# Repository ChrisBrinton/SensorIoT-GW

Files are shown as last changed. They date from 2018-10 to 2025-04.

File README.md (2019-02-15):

# SensorIoT-GW

The SensorIoT GW project is the set of PCB files and the firmware for the the gateway element of the SensorIoT system. It uses an ESP8266 for MCU and Wifi capabilities and an RFM69 packet radio for communicating with the battery operated nodes.

## PCB cad files
Are located in the PCBs folder and use EAGLE cad format (more info [here](https://www.autodesk.com/products/eagle/overview))

## Firmware
More info in the firmware folder.

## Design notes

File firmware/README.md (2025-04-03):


# The firmware for the SensorIoT GW

The firmware is based on Xose Perez project [RFM69GW](https://bitbucket.org/xoseperez/rfm69gw) which has been modified to include a display as well as working with the SensorIoT App and server side as well as moving to the RFM95 Lora radio.

## Installation

### Prerequisits
The firmware project uses Platformio to manage and build. The recommended environment for running Platformio is [VSCode](https://code.visualstudio.com/). After installing VSCode, you can search for the Platformio Extension and install. Platformio can be used command line only if needed. Further details can be found at [Platformio.org](https://platformio.org/)

You'll need the VCP (Virtual Com Port) drivers from [here](https://www.silabs.com/products/development-tools/software/usb-to-uart-bridge-vcp-drivers)

And of course you'll need [git](https://www.git-scm.com/downloads) and [node](https://nodejs.org/en/) if you dont have already

Then the following will install the repo and build:

    git clone https://github.com/ChrisBrinton/SensorIoT-GW
    cd SensorIoT-GW/firmware
    npm install
    pio run

If the build fails due to errors such as

    .pio\libdeps\node\ESP Async WebServer_ID306\src\WebHandlers.cpp:78:25: error: 'time' was not declared in this scope

You'll need to remove .pio\libdeps\node\Time_ID44\Time.h. This error happens on windows due to a lack of case sensitivity between Time.h (not needed for this project) and time.h (needed for this project)

To deploy to your device you need to upload both the SPIFFS filesystem that contains the static web data and the initial settings, then the firmware code:
    To build the static web pages:
        gulp
    To upload filesystem (including static web pages):
        pio run --target uploadfs -e node
    To upload firmware:
        pio run --target upload -e node

## Publishing

The GW publishes to MQTT in the following way:

The topic format for our backend looks like:
/<prefix>/<hostname>/<node_id>/<data_type>/<data>

 <prefix> is GDESGW1 for no particular reason other than I needed something to differentiate messages at a high level in case I wanted to use the broker for a completely different set of messages. For those trivia minded, it stands for GeekDayEnvironmentSensorGateWay model 1

<hostname> is a unique 6 digit number. Just pick one for each independent MQTT publisher

<node_id> is for each differentiated sensor cluster from the hostname. So you could publish two different temp readings from the same MQTT publisher by changing the node #

<data_type> is the sensor data type along the lines of H for humidity, P for pressure and F for temperature (sorry metric users)

<data> is the (presumably) numeric value (assumed to be a float of not too many decimal places)

There are a couple of builtin monitoring data types as well that can be safely ignored if you arent using my hardware: BAT for battery voltage and RSSI for signal strength of the node

That all boils down to a real message that looks like:
/GDESGW1/141188/1/F/78.33

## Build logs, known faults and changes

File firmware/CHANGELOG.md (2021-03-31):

# SensorIoT-GW change log

## [1.1.6]

### Added
- Logging for webserver in hopes of tracking down stability issues

### Changed
- Display Batt values for 3V battery (2xAA) battery more correctly
### Fixed
- Set NTP config to be correct for USA.
## [1.1.5]
### Changed

- Updated settings save to only restart Wifi if Wifi settings changed.
- Heartbeat the heap size even if not connected to MQTT

### Fixed

- Disable local DNS server in AP mode as there is a memory leak that needs to be tracked down.

## [1.1.4]
### Changed

- Updated the following to improve TCP stability
    - Updated platformio core to 2.2.3 (arduino core 2.5.2)
    - Updated ESPAsyncTCP to 1.2.2
    - Updated ESP Async WebServer to 1.2.3
    - Updated RadioHead@1.97 (required for new esp/platformio core)

## [1.1.3]
### Fixed

- Updated NtpClientLib to current version to resolve issue with USA DST calculation

## [1.1.2]

### Changed

- Updated MQTT keepalive time to 240s to be creater than ping interval (60s) on branch using RadioHead radio lib

## [1.0.10] 10/22/2019

### Changed

- Updated MQTT keepalive time to 240s to be creater than ping interval (60s) on branch using lowpowerlab radio lib

## [1.1.1] 9/26/2019

### Changed

- Moved to Radiohead radio library so support RFM95 LoRa radios. This is a pin compatible radio to the RFM69HCW which was used in the previous HW.

### Added

- Supports LTR-329 ambient light sensor and digipot controlled display voltage. This is new in GW HW 1.15 and above. The ambient light is measured using the sensor and the display is adjusted based on this value and the display brightness setting which has been added to the config web pages in the display section.
- The radiohead library is used in the reliable datagram mode where the nodes and the GW exchange ACKs to confirm message receipt. The ACKing will stop on the node side after some number of minutes to conserve node battery life. While the ACKs are happening, TX strength on the node side is tuned.

### Fixed

- Fixed bug in nodelist that caused a crash when deleting an element.

## [1.0.9] 6/18/2019

### Changed

- Reorganized main display code to move slowly side to side (1px/m) to wear OLED displays evenly.
- Updated startup logo to SensorIoT

### Added

- Display has optional shutdown hours, configurable in web config

### Fixed

- Locked platformio core to 2.0.4 to resolve instability

## [1.0.8] 2/18/2019

### Changed

- Updated JustWifi lib to 2.0.2 and refactored to support
- Updated backwards compatible libs to current versions:
  - AsyncMqttClient@0.8.2
  - ESPAsyncTCP@1.2.0
  - ArduinoJson@5.13.4
  - Adafruit GFX Library@b920674
  - ES PAsync WebServer@1.2.0
  - NtpClientLib@2.5.1
  - Sparkfun BME280@2.0.4
  - RFM69@ebf2cb86ff
- Installation directions more complete

### Fixed

- Updated platformio.ini to fix ESP Async WebServer and RFM69 lib defs
- Changed battery thresholds to be more accomodating to 1.5v battery ranges.

### Added

- GW now retrieves nickname from server via MQTT and displays the shortname when available rather than ID:#

## [1.0.7] 1/10/2019

### Added

- Completed support for http firmware upload for both FW and SPIFFS

### Changed

- Display logic is now non-blocking

## [1.0.6] 1/2/2019

### Added

- Initial support for http firmware upload

## [1.0.5] 12/20/2018

### Fixed

- Convert getTopicMapping to string from char\* in effort to eliminate bad topic publishes
- Fix for display of time ending in 1/4/9 shifting and not being centered.

## [1.0.4] 10/1/2018

### Added

- Add erase all firmware function to settings - bring firmware back to factory default

## [1.0.3] 7/1/2018

### Added

- Added display logic to show node 1 data and received node info on display while in AP mode. This allows full HW testing without configuring wifi

### Changed

- Publish node 1 data to MQTT. Packet parsing reworked to facilitate.

## [1.0.0] 7/1/2017

### Added

- Initial version
- Fork of [RFM69GW](https://bitbucket.org/xoseperez/rfm69gw/overview) by Xose Perez over on bitbucket
- Added 128x32 pixel OLED display (based on SSD1305 display driver) to show time and node data

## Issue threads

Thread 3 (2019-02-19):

Add support for LoRa radios

ChrisBrinton, 2019-02-19:
The current RFM69 library used (from lowpowerlabs) does not support the RFM95 LoRa radios. The GW should either move to the rocketlabs library (that supports both) or at least use it to support RFM95 radios. Needs investigation to determine best route.

ChrisBrinton, 2019-02-19:
The suggested lib is [RadioHead](https://www.airspayce.com/mikem/arduino/RadioHead/index.html)

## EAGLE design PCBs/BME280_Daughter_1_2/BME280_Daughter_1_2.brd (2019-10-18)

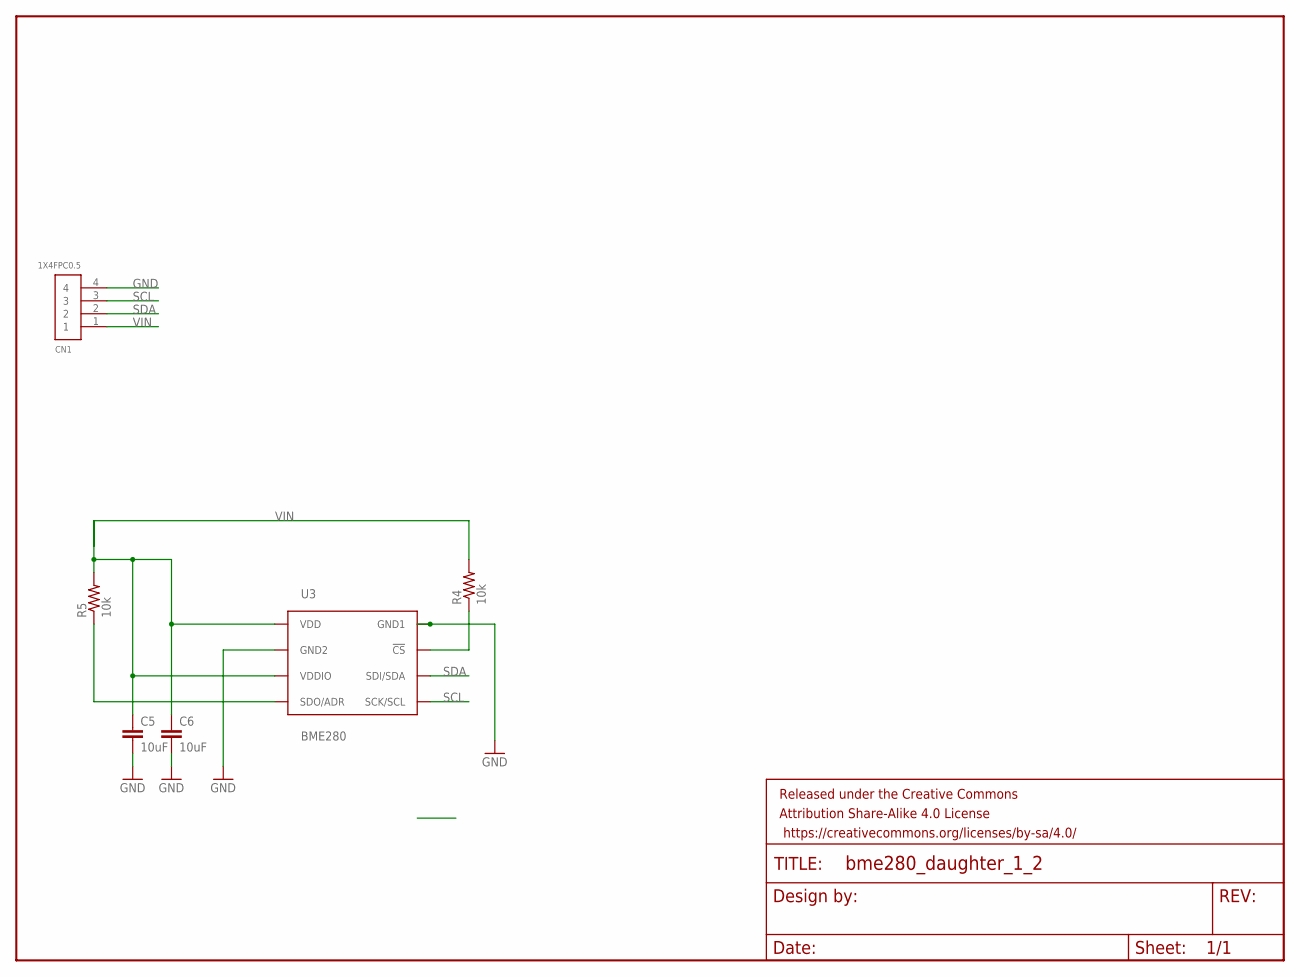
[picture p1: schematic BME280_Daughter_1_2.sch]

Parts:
C5, C6: 10uF; 0805
CN1: 1X4FPC0.5; FPC_0.5MM-4
FRAME1: FRAME-LETTER; CREATIVE_COMMONS
R4, R5: 10k; 0805
U3: BME280; BME280_LGA

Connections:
GND: C5.2, C6.2, CN1.4, U3.P$1 (GND1), U3.P$7 (GND2)
unnamed: R4.1, U3.P$2 (!CS)
unnamed: R5.1, U3.P$5 (SDO/ADR)
SCL: CN1.3, U3.P$4 (SCK/SCL)
SDA: CN1.2, U3.P$3 (SDI/SDA)
VIN: C5.1, C6.1, CN1.1, R4.2, R5.2, U3.P$6 (VDDIO), U3.P$8 (VDD)

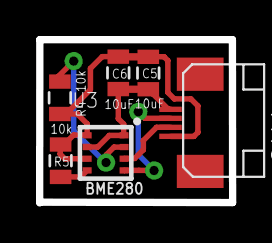
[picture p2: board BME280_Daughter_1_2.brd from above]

Board: 2 copper layers, 10.7 x 9.1 mm, 7 parts (0 on the bottom side), 6 nets.

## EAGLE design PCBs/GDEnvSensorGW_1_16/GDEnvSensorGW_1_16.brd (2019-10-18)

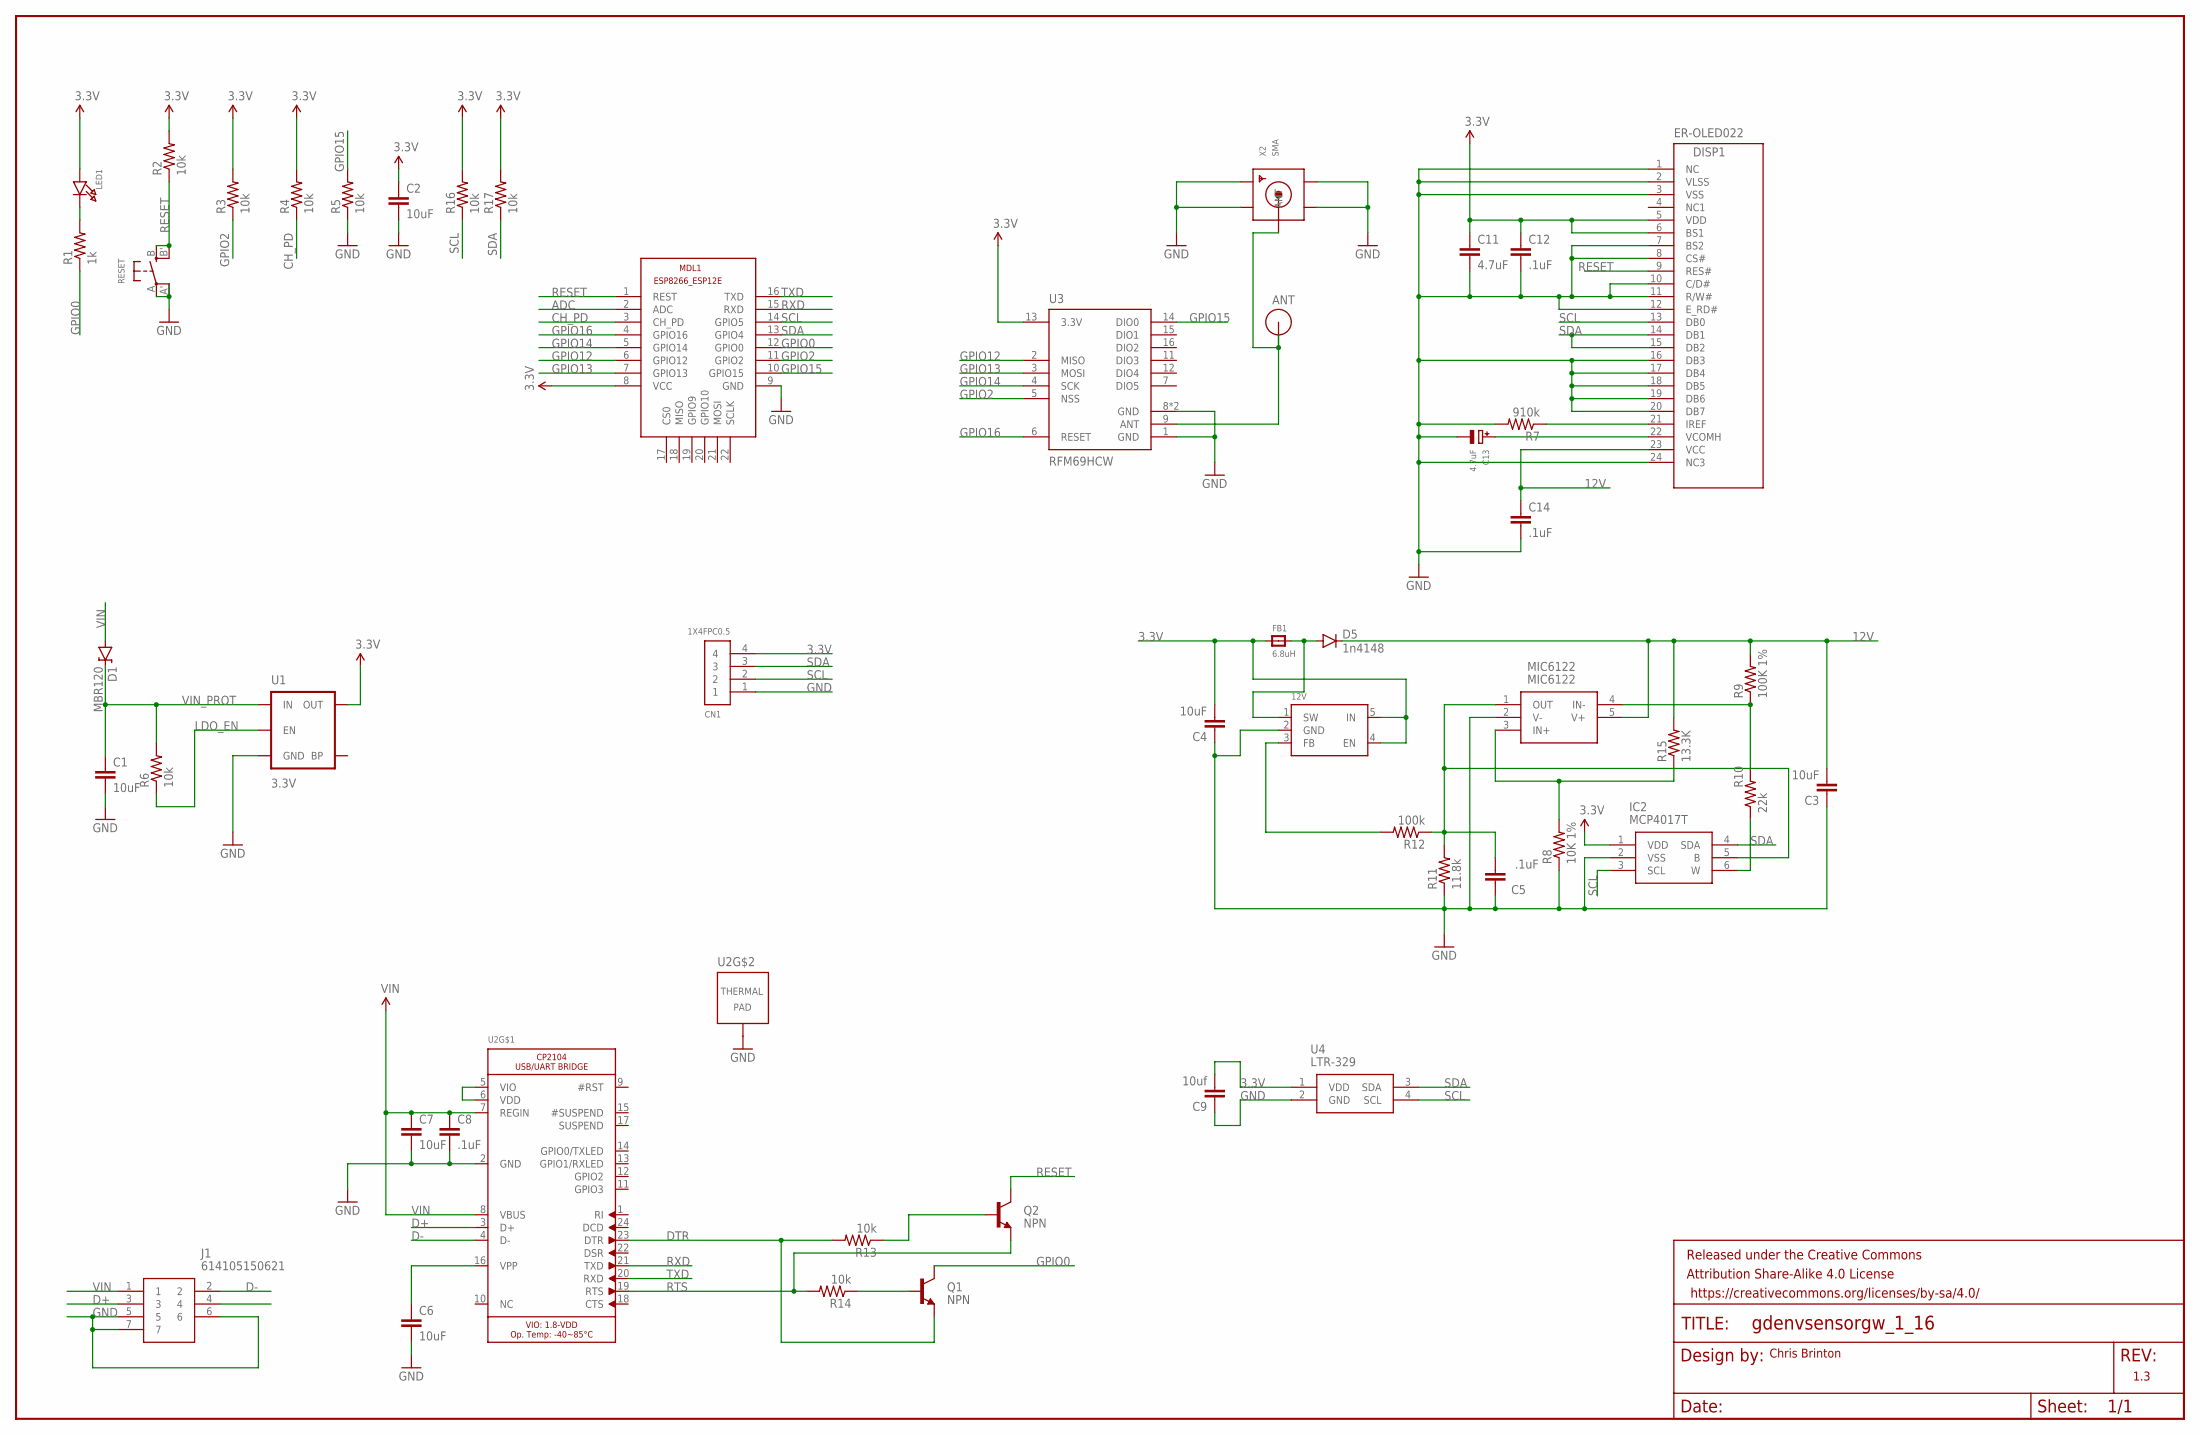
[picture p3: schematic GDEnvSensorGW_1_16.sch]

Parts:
12V: MP1541_SOT23-5; SOT23-5
ANT: RFM12B_ANTENNA; RFM12B-ANTENNA
C1, C2, C3, C4, C6, C7: 10uF; 0805-CAP
C5, C8, C12, C14: .1uF; 0805-CAP
C9: 10uf; 0805-CAP
C11: 4.7uF; 0805-CAP
C13: 4.7uF; EIA3216-18/A-R
CN1: 1X4FPC0.5; FPC_0.5MM-4
D1: MBR120; SOD-123
D5: 1n4148; SOD-323
DISP1: ER-OLED022
FB1: 6.8uH; _0805
FRAME1: FRAME-LEDGER; CREATIVE_COMMONS
IC2: MCP4017T; SOT65P210X110-6N
J1: 614105150621
LED1: LED0805; CHIPLED_0805
MDL1: ESP8266-ESP12F; ESP8266-ESP12E
MIC6122: MIC6122; SOT95P280X145-5N
Q1, Q2: NPN; SOT23-3
R1: 1k; R0805
R2, R3, R4, R5, R6, R13, R14, R16, R17: 10k; R0805
R7: 910k; R0805
R8: 10K 1%; R0805
R9: 100K 1%; R0805
R10: 22k; R0805
R11: 11.8k; R0805
R12: 100k; R0805
R15: 13.3K; R0805
RESET: SWITCH_TACT_SMT4.6X2.8; BTN_KMR2_4.6X2.8
U1: 3.3V; SOT23-5
U2: CP2104; QFN24_4MM_SMSC
U3: RFM69HCW; RFM69HCW-XXXS2
U4: LTR-329; LTR329ALS01
X2: SMA; SMA_EDGELAUNCH_UFL

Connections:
3.3V: 12V.4 (EN), 12V.5 (IN), C2.1, C4.2, C9.2, C11.1, C12.1, CN1.4, DISP1.5 (VDD), DISP1.6 (BS1), FB1.1, IC2.1 (VDD), LED1.A, MDL1.8 (VCC), R2.2, R3.2, R4.2, R16.2, R17.2, U1.5 (OUT), U3.13 (3.3V), U4.1 (VDD)
12V: C3.2, C14.1, D5.C, DISP1.23 (VCC), MIC6122.5 (V+), R9.2, R15.2
ADC: MDL1.2 (ADC)
ANT: ANT.P$1, U3.9 (ANT), X2.P (ANT)
CH_PD: MDL1.3 (CH_PD), R4.1
D+: J1.3, U2.3 (D+)
D-: J1.2, U2.4 (D-)
DTR: Q1.2 (E), R13.2, U2.23 (DTR)
GND: 12V.2 (GND), C1.2, C2.2, C3.1, C4.1, C5.1, C6.2, C7.2, C8.2, C9.1, C11.2, C12.2, C13.-, C14.2, CN1.1, DISP1.1 (NC), DISP1.2 (VLSS), DISP1.3 (VSS), DISP1.7 (BS2), DISP1.8 (CS#), DISP1.10 (C/D#), DISP1.11 (R/W#), DISP1.12 (E_RD#), DISP1.16 (DB3), DISP1.17 (DB4), DISP1.18 (DB5), DISP1.19 (DB6), DISP1.20 (DB7), DISP1.24 (NC3), IC2.2 (VSS), J1.5, J1.6, J1.7, MDL1.9 (GND), MIC6122.2 (V-), R5.1, R7.2, R8.1, R11.1, RESET.A, RESET.A' (P1), U1.2 (GND), U2.2 (GND), U2.THERM (TP), U3.1 (GND), U3.8 (GND), U3.10 (GND), U4.2 (GND), X2.GND@1 (GND1), X2.GND@2 (GND2), X2.GND@3 (GND3), X2.GND@4 (GND4)
GPIO0: MDL1.12 (GPIO0), Q1.3 (C), R1.1
GPIO2: MDL1.11 (GPIO2), R3.1, U3.5 (NSS)
GPIO12: MDL1.6 (GPIO12), U3.2 (MISO)
GPIO13: MDL1.7 (GPIO13), U3.3 (MOSI)
GPIO14: MDL1.5 (GPIO14), U3.4 (SCK)
GPIO15: MDL1.10 (GPIO15), R5.2, U3.14 (DIO0)
GPIO16: MDL1.4 (GPIO16), U3.6 (RESET)
LDO_EN: R6.1, U1.3 (EN)
unnamed: U2.5 (VIO), U2.6 (VDD)
unnamed: MIC6122.3 (IN+), R8.2, R15.1
unnamed: LED1.C, R1.2
unnamed: C13.+, DISP1.22 (VCOMH)
unnamed: C6.1, U2.16 (VPP)
unnamed: C5.2, IC2.5 (B), MIC6122.1 (OUT), R11.2, R12.1
unnamed: MIC6122.4 (IN-), R9.1, R10.2
unnamed: 12V.1 (SW), D5.A, FB1.2
unnamed: Q2.1 (B), R13.1
unnamed: DISP1.21 (IREF), R7.1
unnamed: IC2.6 (W), R10.1
unnamed: 12V.3 (FB), R12.2
unnamed: Q1.1 (B), R14.1
RESET: DISP1.9 (RES#), MDL1.1 (REST), Q2.3 (C), R2.1, RESET.B (S), RESET.B' (S1)
RTS: Q2.2 (E), R14.2, U2.19 (RTS)
RXD: MDL1.15 (RXD), U2.21 (TXD)
SCL: CN1.2, DISP1.13 (DB0), IC2.3 (SCL), MDL1.14 (GPIO5), R16.1, U4.4 (SCL)
SDA: CN1.3, DISP1.14 (DB1), DISP1.15 (DB2), IC2.4 (SDA), MDL1.13 (GPIO4), R17.1, U4.3 (SDA)
TXD: MDL1.16 (TXD), U2.20 (RXD)
VIN: C7.1, C8.1, D1.A, J1.1, U2.7 (REGIN), U2.8 (VBUS)
VIN_PROT: C1.1, D1.C, R6.2, U1.1 (IN)

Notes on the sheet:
Chris Brinton
1.3

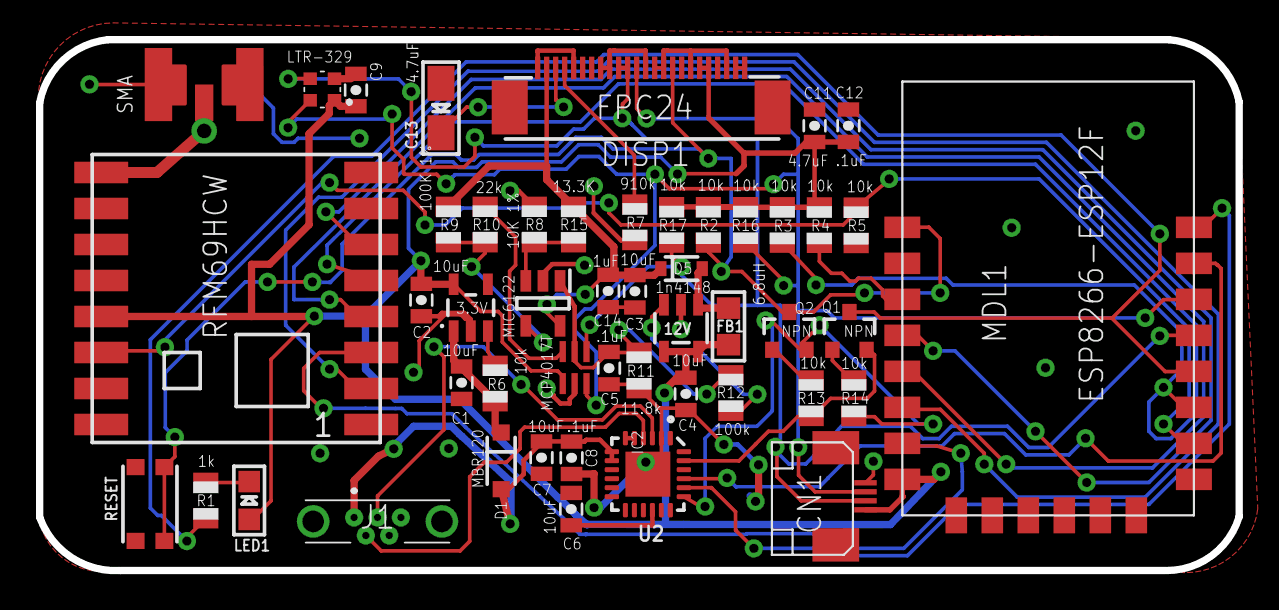
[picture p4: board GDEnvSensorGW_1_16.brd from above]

Board: 2 copper layers, 66.6 x 29.5 mm, 51 parts (0 on the bottom side), 37 nets.

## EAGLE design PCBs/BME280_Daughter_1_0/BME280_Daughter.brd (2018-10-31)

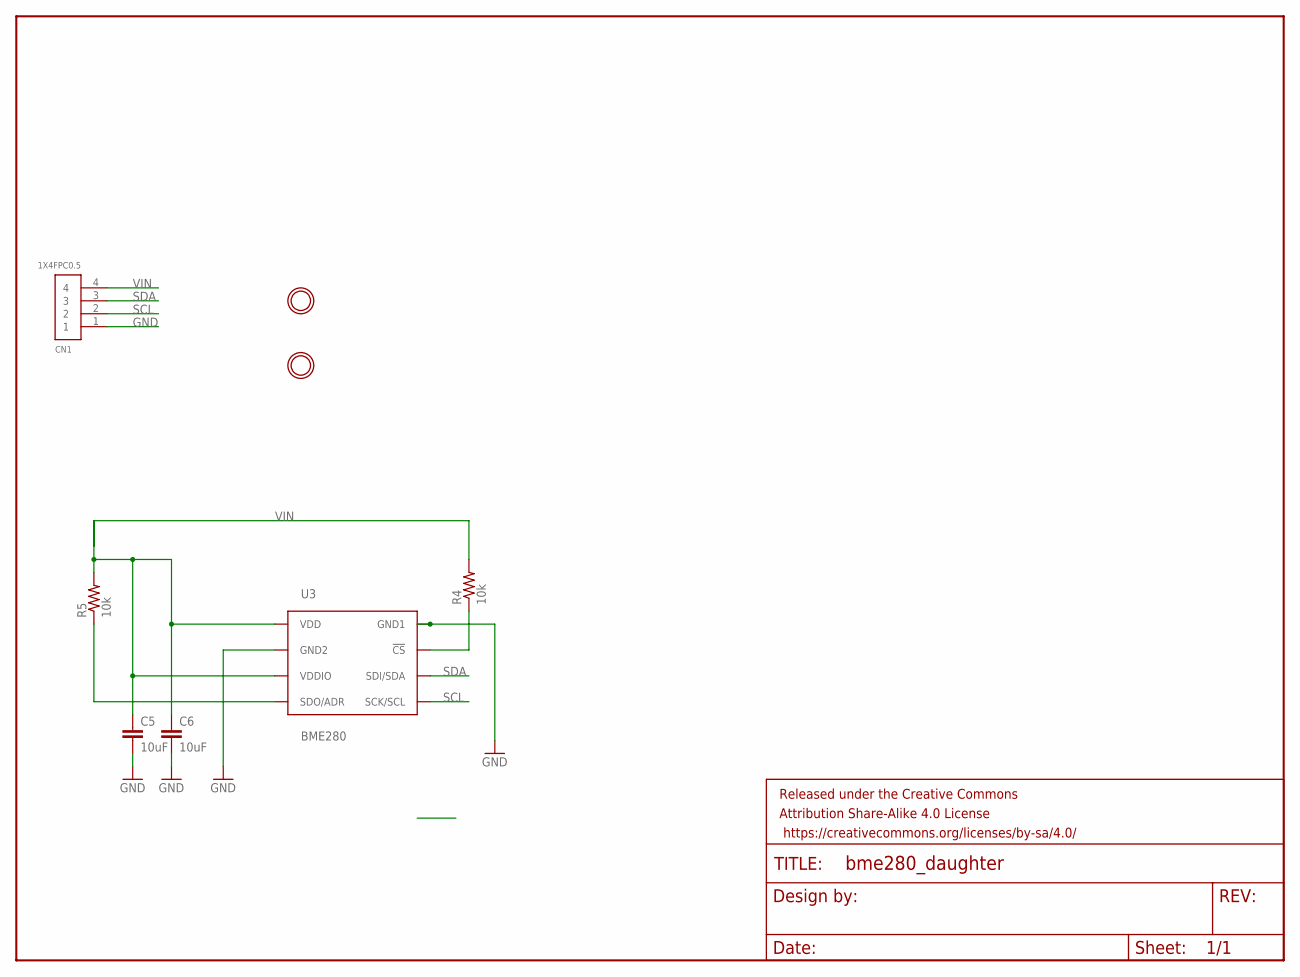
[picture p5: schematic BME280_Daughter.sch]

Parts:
C5, C6: 10uF; 0805
CN1: 1X4FPC0.5; FPC_0.5MM-4
FRAME1: FRAME-LETTER; CREATIVE_COMMONS
R4, R5: 10k; 0805
U3: BME280; BME280_LGA
U$1, U$2: MOUNTINGHOLE2.0; MOUNTINGHOLE_2.0_PLATED

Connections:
GND: C5.2, C6.2, CN1.1, U3.P$1 (GND1), U3.P$7 (GND2)
unnamed: R4.1, U3.P$2 (!CS)
unnamed: R5.1, U3.P$5 (SDO/ADR)
SCL: CN1.2, U3.P$4 (SCK/SCL)
SDA: CN1.3, U3.P$3 (SDI/SDA)
VIN: C5.1, C6.1, CN1.4, R4.2, R5.2, U3.P$6 (VDDIO), U3.P$8 (VDD)

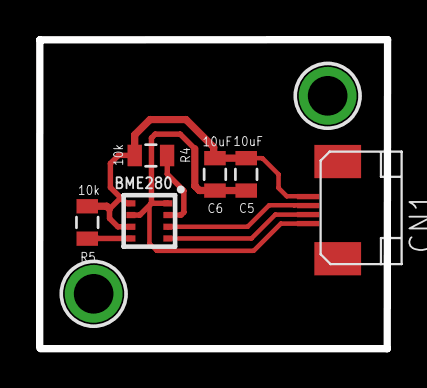
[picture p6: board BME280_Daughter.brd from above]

Board: 2 copper layers, 19.3 x 17.2 mm, 9 parts (0 on the bottom side), 6 nets.

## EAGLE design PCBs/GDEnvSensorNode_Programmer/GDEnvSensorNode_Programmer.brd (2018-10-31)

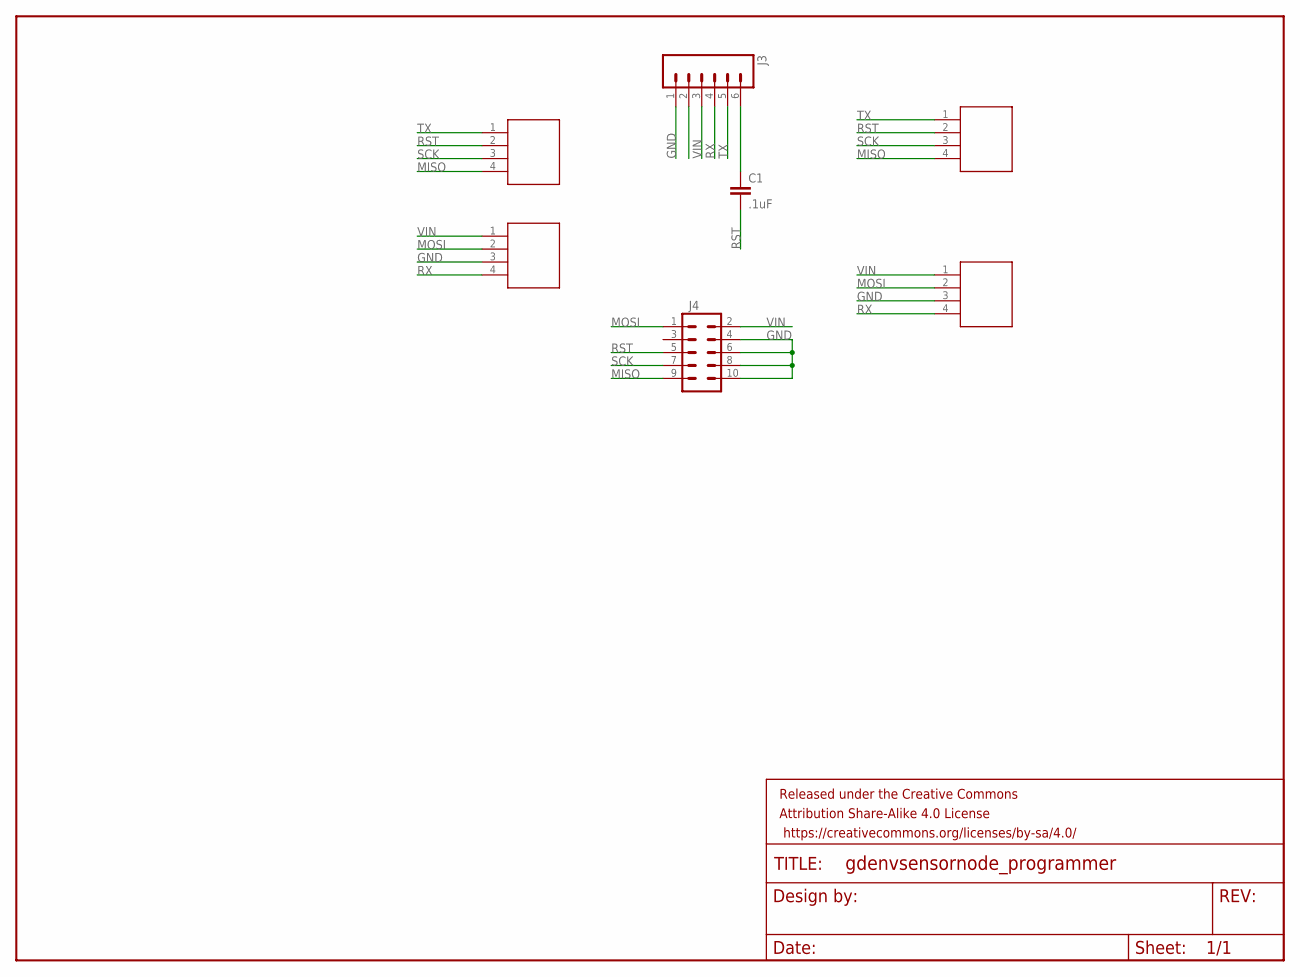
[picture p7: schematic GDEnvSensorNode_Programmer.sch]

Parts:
C1: .1uF; 0805
FRAME1: FRAME-LETTER; CREATIVE_COMMONS
J1, J2, J5, J6: 4X.1IN_POGO_PIN
J3: M06LONGPADS; 1X06_LONGPADS
J4: M05X2PTH; AVR_ICSP

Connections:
GND: J2.3, J3.1, J4.4, J4.6, J4.8, J4.10, J6.3
MISO: J1.4, J4.9, J5.4
MOSI: J2.2, J4.1, J6.2
unnamed: C1.1, J3.6
RST: C1.2, J1.2, J4.5, J5.2
RX: J2.4, J3.4, J6.4
SCK: J1.3, J4.7, J5.3
TX: J1.1, J3.5, J5.1
VIN: J2.1, J3.3, J4.2, J6.1

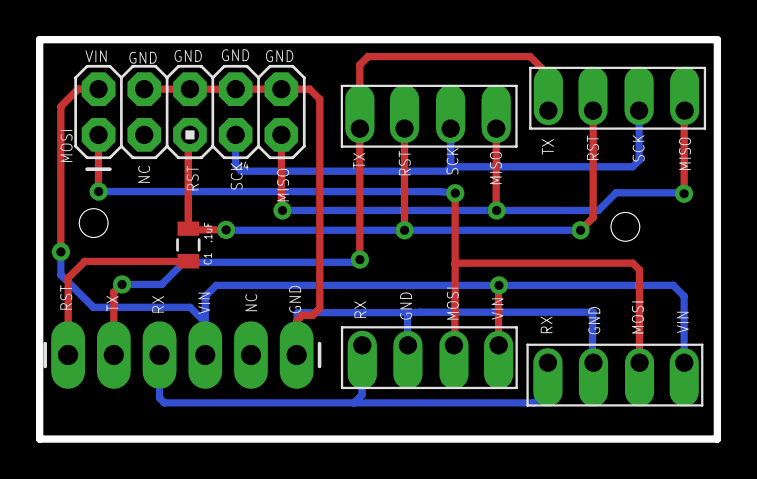
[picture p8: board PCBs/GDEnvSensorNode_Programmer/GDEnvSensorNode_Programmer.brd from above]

Board: 2 copper layers, 37.6 x 22.2 mm, 8 parts (0 on the bottom side), 9 nets.

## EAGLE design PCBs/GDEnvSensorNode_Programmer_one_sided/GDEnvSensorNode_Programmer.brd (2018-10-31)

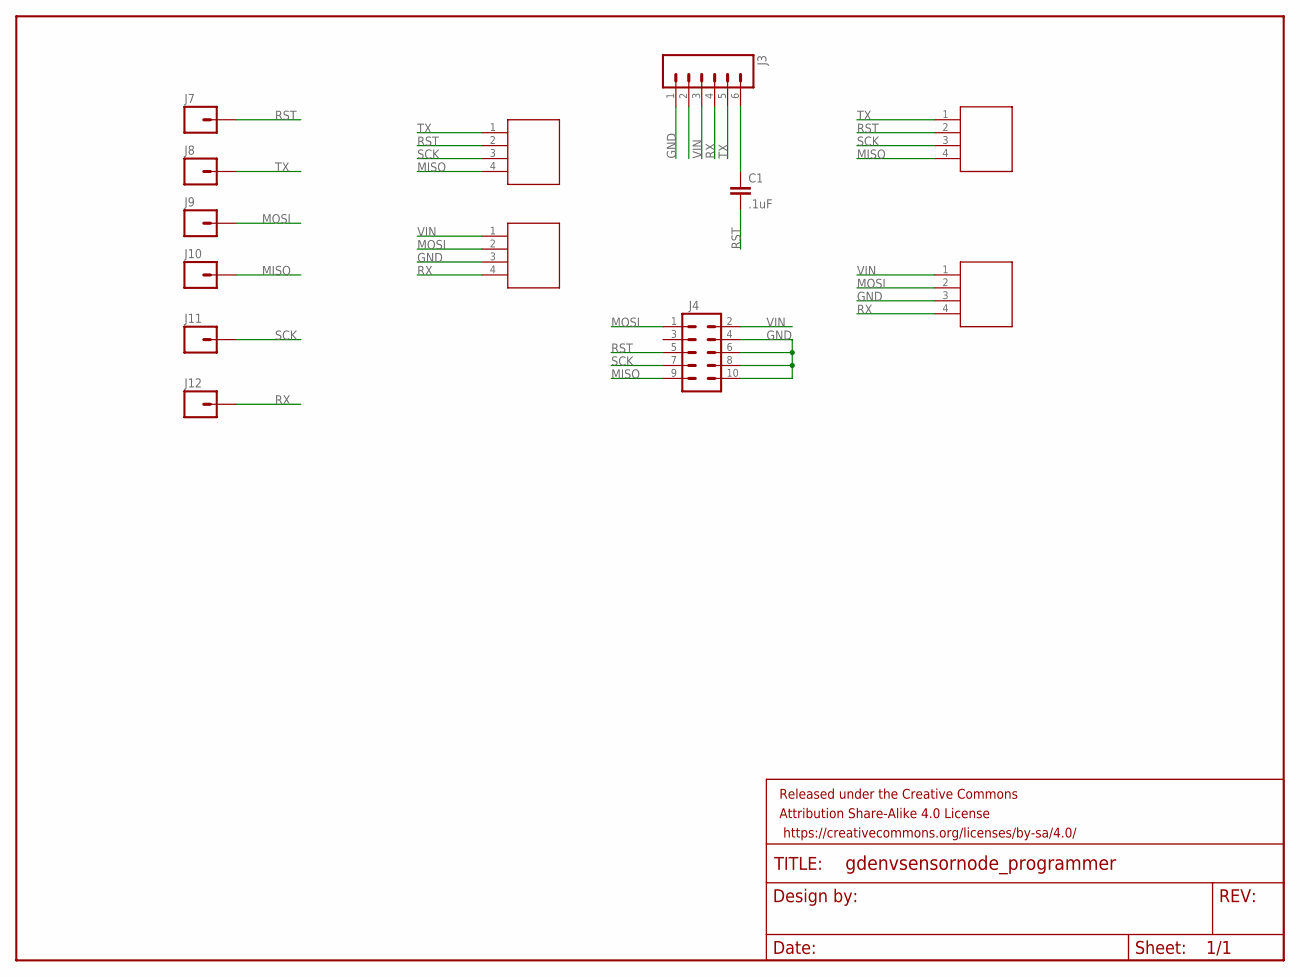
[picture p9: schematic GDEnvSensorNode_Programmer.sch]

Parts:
C1: .1uF; 0805
FRAME1: FRAME-LETTER; CREATIVE_COMMONS
J1, J2, J5, J6: 4X.1IN_POGO_PIN
J3: M06LONGPADS; 1X06_LONGPADS
J4: M05X2PTH; AVR_ICSP
J7, J8, J9, J10, J11, J12: M01PTH; 1X01

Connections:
GND: J2.3, J3.1, J4.4, J4.6, J4.8, J4.10, J6.3
MISO: J1.4, J4.9, J5.4, J10.1
MOSI: J2.2, J4.1, J6.2, J9.1
unnamed: C1.1, J3.6
RST: C1.2, J1.2, J4.5, J5.2, J7.1
RX: J2.4, J3.4, J6.4, J12.1
SCK: J1.3, J4.7, J5.3, J11.1
TX: J1.1, J3.5, J5.1, J8.1
VIN: J2.1, J3.3, J4.2, J6.1

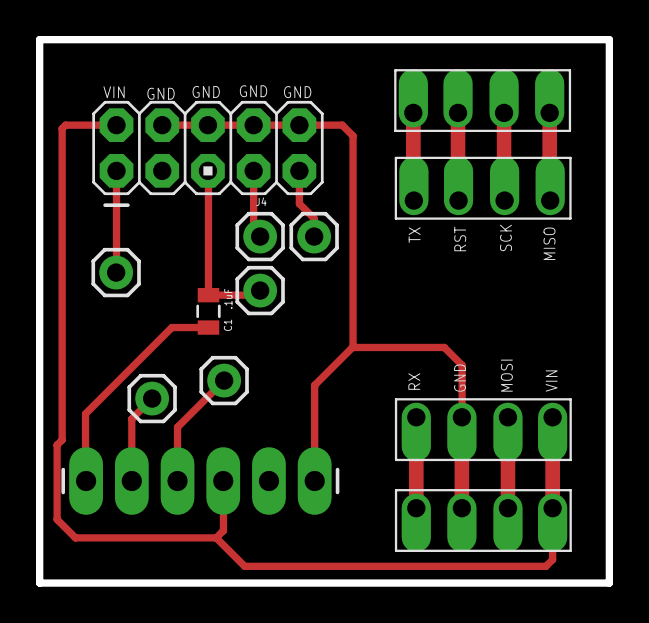
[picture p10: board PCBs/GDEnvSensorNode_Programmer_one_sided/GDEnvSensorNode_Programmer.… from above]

Board: 2 copper layers, 31.6 x 30.2 mm, 14 parts (0 on the bottom side), 9 nets.

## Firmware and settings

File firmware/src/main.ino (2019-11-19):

/*

SensorIoT-GW
MAIN MODULE

ESP8266 based wifi to radio Gateway
Gateway code with suport for ESP8266-based boards

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
Based on the RFM69GW project by Xose Perez

Copyright (C) 2016-2017 by Xose Pérez <xose dot perez at gmail dot com>

Forked/Updated 2017-2018 by Chris Brinton for the SensorIoT project

*/

#include <Arduino.h>
#include "config/all.h"

// -----------------------------------------------------------------------------
// Prototypes
// -----------------------------------------------------------------------------
#include <NtpClientLib.h>
#include <ESPAsyncWebServer.h>
#include <AsyncMqttClient.h>
#include <JustWifi.h>
#include <ArduinoJson.h>
#include "RadioHeadManager.h"
#include "FS.h"
#include "NodeList.h"
template<typename T> String getSetting(const String& key, T defaultValue);
template<typename T> bool setSetting(const String& key, T value);

struct _GDnode_t {
  String RSSI = "";
  String BAT = "";
  String F = "";
  String H = "";
  String P = "";
  String shortname = "";
  String longname = "";
};

struct _node_t {
  unsigned long count = 0;
  unsigned long missing = 0;
  unsigned long duplicates = 0;
  unsigned char lastPacketID = 0;
  uint8_t messageID = 0;
  uint8_t senderID = 0;
  uint8_t targetID = 0;
  uint8_t packetID = 0;
  _GDnode_t* THP;
};

_node_t nodeInfo[255];

NodeList nodeList;

//
// -----------------------------------------------------------------------------
// METHODS
// -----------------------------------------------------------------------------


String getIdentifier() {
    char identifier[20];
    sprintf(identifier, "%s_%06X", DEVICE, ESP.getChipId());
    return String(identifier);
}

void ledOn() {
    digitalWrite(LED_PIN, LOW);
}

void ledOff() {
    digitalWrite(LED_PIN, HIGH);
}

void blink(unsigned int delayms, unsigned char times = 1) {
    for (unsigned char i=0; i<times; i++) {
        if (i>0) delay(delayms);
        ledOn();
        delay(delayms);
        ledOff();
    }
}

void clearCounts() {
    for(unsigned int i=0; i<255; i++) {
        nodeInfo[i].duplicates = 0;
        nodeInfo[i].missing = 0;
    }
}

void sendSensorData() {
  sendNodeToMQTT(&nodeInfo[1]);
}

void getNicknames() {
    
    static bool nicknamesRequested = false;

    if(!nicknamesRequested) {

        // get command topic from config and replace placeholder strings
        String commandTopic = getSetting("mqttCommandTopic", MQTT_COMMAND_TOPIC);
        String tmpHN = String(getSetting("hostname", APP_NAME));
        tmpHN.replace("_","/");
        commandTopic.replace("{hostname}", tmpHN);

        if ((WiFi.status() == WL_CONNECTED) && (mqttConnected())) {
            nicknamesRequested = true;
            mqttSend((char*)commandTopic.c_str(), (char*)"get_nicknames");
            DEBUG_MSG("[DISPLAY] Nicknames requested via MQTT\n");
        
        } 
    }
}

void setNickname(char* json) {
    // Parse JSON input
    const size_t capacity = JSON_OBJECT_SIZE(3)+60;
    DynamicJsonBuffer jsonBuffer(capacity);;
    JsonObject& root = jsonBuffer.parseObject(json);

    if (!root.success()) {
        DEBUG_MSG("[REPLY] Nickname reply not deserializable. Ignoring\n");
        return;
    }
    int node_id = root["node_id"];
    const char* shortname = root["shortname"];
    const char* longname = root["longname"];
    if(nodeInfo[node_id].THP == 0) {
      nodeInfo[node_id].THP = new _GDnode_t;
    }
    nodeInfo[node_id].THP->shortname = shortname;
    nodeInfo[node_id].THP->longname = longname;

}

void processCommandReply(char* topic, char* reply) {
    String sTopic = topic;
    String sReply = reply;

    int index = sTopic.lastIndexOf('/') + 1;
    String command = sTopic.substring(index, sTopic.length());
    if(command == "get_nicknames") {
        DEBUG_MSG("[REPLY] Processing get_nicknames command response\n");
        setNickname(reply);
    } else if (command == "get_config") {
        DEBUG_MSG("[REPLY] Processing get_config command response\n");
    } else {
        DEBUG_MSG("[REPLY] Unrecognized command reply %s\n", command.c_str());
    }

}

void processMessage(packet_t * data) {

    blink(5, 1);

    DEBUG_MSG(
        "[MESSAGE] messageID:%lu senderID:%d targetID:%d packetID:%d rssi:%d\n",
        data->messageID,
        data->senderID,
        data->targetID,
        data->packetID,
        data->rssi
    );

    DEBUG_MSG("[MESSAGE] processing %d pairs\n", data->pairCount);
    for (uint8_t i=0;i<data->pairCount;i++){
      DEBUG_MSG("[MESSAGE] name: %s value: %s\n", data->pairs[i].name, data->pairs[i].value);
    }

    // Detect duplicates and missing packets
    // packetID==0 means device is not sending packetID info
    //DEBUG_MSG("[MESSAGE] checking for dups and gaps\n");
    if (data->packetID > 0) {
        if (nodeInfo[data->senderID].count > 0) {

            unsigned char gap = data->packetID - nodeInfo[data->senderID].lastPacketID;

            if (gap == 0) {
                DEBUG_MSG(" DUPLICATED\n");
                nodeInfo[data->senderID].duplicates = nodeInfo[data->senderID].duplicates + 1;
                return;
            }

            if ((gap > 1) && (data->packetID > 1)) {
                DEBUG_MSG(" MISSING PACKETS!!\n");
                nodeInfo[data->senderID].missing = nodeInfo[data->senderID].missing + gap - 1;
            }
        }

    }

    //DEBUG_MSG("[MESSAGE] Packaging into nodeInfo\n");
    nodeInfo[data->senderID].lastPacketID = data->packetID;
    nodeInfo[data->senderID].count = nodeInfo[data->senderID].count + 1;
    nodeInfo[data->senderID].senderID = data->senderID;
    nodeInfo[data->senderID].targetID = data->targetID;
    nodeInfo[data->senderID].messageID = data->messageID;
    nodeInfo[data->senderID].packetID = data->packetID;

    if(nodeInfo[data->senderID].THP == 0) {
      nodeInfo[data->senderID].THP = new _GDnode_t;
    }
    nodeInfo[data->senderID].THP->RSSI = data->rssi;

    if(!nodeList.nodeExists(data->senderID)){
      nodeList.insertNode(data->senderID);
    }
    //DEBUG_MSG("[MESSAGE] nodeInfo created\n");

    //Set the time that we got the message. If it goes too long without another update, the diplay routing will clear is out.
    nodeList.setUpdateTime(data->senderID, time(NULL));

    //DEBUG_MSG("[MESSAGE] putting name-value pairs into nodeInfo\n");
    for (uint8_t j=0;j<data->pairCount;j++) {
        if(strncmp(data->pairs[j].name,"F",1) == 0){
        nodeInfo[data->senderID].THP->F = data->pairs[j].value;
        }
        if(strncmp(data->pairs[j].name,"H",1) == 0){
        nodeInfo[data->senderID].THP->H = data->pairs[j].value;
        }
        if(strncmp(data->pairs[j].name,"P",1) == 0){
        nodeInfo[data->senderID].THP->P = data->pairs[j].value;
        }
        if(strncmp(data->pairs[j].name,"BAT",1) == 0){
        nodeInfo[data->senderID].THP->BAT = data->pairs[j].value;
        }

        // Send info to websocket clients
        char buffer[150];
        
        //DEBUG_MSG("SenderID: %u\n", data->senderID);
        //DEBUG_MSG("TargetID: %u\n", data->targetID);
        //DEBUG_MSG("PacketID: %u\n", data->packetID);
        //DEBUG_MSG("Name: %s\n", data->pairs[j].name);
        //DEBUG_MSG("Value: %s\n", data->pairs[j].value);
        //DEBUG_MSG("RSSI: %d\n", data->rssi);
        //DEBUG_MSG("Dups: %u\n", nodeInfo[data->senderID].duplicates);
        //DEBUG_MSG("Missing: %u\n", nodeInfo[data->senderID].missing);
        
        sprintf_P(
            buffer,
            PSTR("{\"packet\": {\"senderID\": %u, \"targetID\": %u, \"packetID\": %u, \"name\": \"%s\", \"value\": \"%s\", \"rssi\": %d, \"duplicates\": %u, \"missing\": %u}}"),
            data->senderID, data->targetID, data->packetID, data->pairs[j].name, data->pairs[j].value, data->rssi,
            nodeInfo[data->senderID].duplicates , nodeInfo[data->senderID].missing);
        wsSend(buffer);

      
      
    }

    sendNodeToMQTT(&nodeInfo[data->senderID]);

}

String getTopicMapping(String ID, String key) {
  String returnTopic = "BLANK";
  // Try to find a matching mapping
  unsigned int count = getSetting("mappingCount", "0").toInt();
  for (unsigned int i=0; i<count; i++) {
      if ((getSetting("nodeid" + String(i)) == ID) &&
          (getSetting("key" + String(i)) == key)) {
          returnTopic = String(String(getSetting("topic" + String(i)).c_str()) + key);
          DEBUG_MSG("[MESSAGE] getTopicMapping returning: %s\n", returnTopic.c_str());
          return returnTopic;
      }
  }

  //If we made it to here, we didnt find a mapping. Return the default topic
  returnTopic = getSetting("defaultTopic", MQTT_DEFAULT_TOPIC);
  if (returnTopic.length() > 0) {
      returnTopic.replace("{nodeid}", ID);
      returnTopic.replace("{key}", key);
      String tmpHN = String(getSetting("hostname", APP_NAME));
      tmpHN.replace("_","/");
      returnTopic.replace("{hostname}", tmpHN);
      returnTopic += "/";
      DEBUG_MSG("[MESSAGE] getTopicMapping returning default topic: %s\n", returnTopic.c_str());
      return returnTopic;
    }
    DEBUG_MSG("[MESSAGE] getTopicMapping returning: BLANK This shouldnt happen\n");
  return returnTopic;
}

void sendNodeToMQTT(_node_t * node) {

  mqttSend((char*) getTopicMapping(String(node->senderID), String("F")).c_str(), (char *) node->THP->F.c_str());
  mqttSend((char*) getTopicMapping(String(node->senderID), String("H")).c_str(), (char *) node->THP->H.c_str());
  mqttSend((char*) getTopicMapping(String(node->senderID), String("P")).c_str(), (char *) node->THP->P.c_str());
  mqttSend((char*) getTopicMapping(String(node->senderID), String("BAT")).c_str(), (char *) node->THP->BAT.c_str());
  mqttSend((char*) getTopicMapping(String(node->senderID), String("RSSI")).c_str(), (char *) node->THP->RSSI.c_str());

}

// -----------------------------------------------------------------------------
// Hardware
// -----------------------------------------------------------------------------

void hardwareSetup() {
	
    Serial.begin(SERIAL_BAUDRATE);
    while(!Serial);

    SPIFFS.begin();
    pinMode(LED_PIN, OUTPUT);
    ledOff();
	
}

void hardwareLoop() {

    // Heartbeat
    static unsigned long last_heartbeat = 0;
    if ((millis() - last_heartbeat > HEARTBEAT_INTERVAL) || (last_heartbeat == 0)) {
        last_heartbeat = millis();
        if (mqttConnected()) {
            String sTopic = getSetting("hbTopic", MQTT_HEARTBEAT_TOPIC);
            String tmpHN = String(getSetting("hostname", APP_NAME));
            tmpHN.replace("_","/");
            sTopic.replace("{hostname}", tmpHN);
            mqttSend((char *) sTopic.c_str(), (char *) String(APP_VERSION).c_str());
            DEBUG_MSG("[NTP] Time: %s\n", (char *) NTP.getTimeDateString().c_str());
        }
        DEBUG_MSG("[BEAT] Free heap: %d\n", ESP.getFreeHeap());
    }

}

void welcome() {

    delay(2000);
    Serial.printf("%s %s\n", (char *) APP_NAME, (char *) APP_VERSION);
    Serial.printf("%s\n%s\n\n", (char *) APP_AUTHOR, (char *) APP_WEBSITE);
    //Serial.printf("Device: %s\n", (char *) getIdentifier().c_str());
    Serial.printf("ChipID: %06X\n", ESP.getChipId());
    Serial.printf("Last reset reason: %s\n", (char *) ESP.getResetReason().c_str());
    Serial.printf("Memory size: %d bytes\n", ESP.getFlashChipSize());
    Serial.printf("Free heap: %d bytes\n", ESP.getFreeHeap());
    FSInfo fs_info;
    if (SPIFFS.info(fs_info)) {
        Serial.printf("File system total size: %d bytes\n", fs_info.totalBytes);
        Serial.printf("            used size : %d bytes\n", fs_info.usedBytes);
        Serial.printf("            block size: %d bytes\n", fs_info.blockSize);
        Serial.printf("            page size : %d bytes\n", fs_info.pageSize);
        Serial.printf("            max files : %d\n", fs_info.maxOpenFiles);
        Serial.printf("            max length: %d\n", fs_info.maxPathLength);
    }
    Serial.println();
    Serial.println();

}

int restartCountdown;

void restartSetup() {
    restartCountdown = 0;
}

void restartLoop() {
    static int lastMillis = 0;
    int nowMillis = millis();
    if(nowMillis > (lastMillis + 1000)) {
        lastMillis = nowMillis;
        if(restartCountdown) {
            restartCountdown--;
            DEBUG_MSG("[RESTART] Restart countdown: %i\n", restartCountdown);
            if(!restartCountdown){
                ESP.restart();
            }
        }
    }
}

void setRestartCountdown(int counter) {
    restartCountdown = counter;
    DEBUG_MSG("[RESTART] Restart countdown set to: %i\n", counter);
}

// -----------------------------------------------------------------------------
// Bootstrap methods
// -----------------------------------------------------------------------------

void setup() {
    

    hardwareSetup();

    welcome();

    settingsSetup();
    if (getSetting("hostname").length() == 0) {
        setSetting("hostname", String() + getIdentifier());
        saveSettings();
    }
    //ensure backwards compatibility
    if(getSetting("mqttEnabled", MQTT_ENABLED) == "true") {
        setSetting("mqttEnabled", "on");
        saveSettings();
    }


    wifiSetup();
    otaSetup();
    mqttSetup();
    radioSetup(); 
    ntpSetup();
    sensorSetup(); 
    displaySetup();     
    webSetup();
    restartSetup();

}

void loop() {

    hardwareLoop();
    settingsLoop();
    wifiLoop();
    otaLoop();
    mqttLoop();
    radioLoop();
    ntpLoop();
    sensorLoop();
    displayLoop();
    restartLoop();
    getNicknames();


    yield();

}

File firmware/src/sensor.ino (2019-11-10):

#include <SparkFunBME280.h>
#include <LTR303.h>
#include <Wire.h>
#include <SPI.h>
#include "config/global.h"

void printI2CError(byte error) {
  // If there's an I2C error, this function will
  // print out an explanation.

  Serial.print("I2C error: ");
  Serial.print(error,DEC);
  Serial.print(", ");
  
  switch(error) {
    case 0:
      Serial.println("success");
      break;
    case 1:
      Serial.println("data too long for transmit buffer");
      break;
    case 2:
      Serial.println("received NACK on address (disconnected?)");
      break;
    case 3:
      Serial.println("received NACK on data");
      break;
    case 4:
      Serial.println("other error");
      break;
    default:
      Serial.println("unknown error");
  }
}

//
// Globals for BME280 Sensor module
//

BME280 bme280;
double F,P,H;
char buffer[50];

//
// Globals for LTR-329 Sensor
//

LTR303 ltr329;
double avgLight;

void sensorSetup(){

  THPSensorSetup();
  if(DISPLAY_HAS_LIGHT_SENSOR) {
    ALSensorSetup();
  }

}

void THPSensorSetup() {

  bme280.settings.commInterface = I2C_MODE;
  bme280.settings.I2CAddress = 0x77;
  bme280.settings.runMode = BME280_RUNMODE; //Normal mode
  bme280.settings.tStandby = BME280_STANDBY;
  bme280.settings.filter = BME280_FILTER;
  bme280.settings.tempOverSample = BME280_OVERSAMPLE;
  bme280.settings.pressOverSample = BME280_OVERSAMPLE;
  bme280.settings.humidOverSample = BME280_OVERSAMPLE;

}

void ALSensorSetup(){

  // Initialize the LTR303 library
  // 100ms 	initial startup time required
  delay(100);

  resetALSensor();

  setALSensor();

  avgLight = 30;

}

// Perform a SW reset of the LTR-329
void resetALSensor() {
  DEBUG_MSG("[SENSOR] Resetting LTR-329\n");
  // You can pass nothing to begin() for the default I2C address (0x29)
  ltr329.begin();
  //Performa a SW reset of the device (gain here is ignored)
  ltr329.setControl(LTR329_GAIN, true, false);
  delay(200); // wait after reset;
}

//Set the control registers of the LTR-329 and start capturing data
void setALSensor() {

  // You can pass nothing to begin() for the default I2C address (0x29)
  ltr329.begin();

  ltr329.setControl(LTR329_GAIN, false, false);

  ltr329.setMeasurementRate(LTR329_INT_TIME,LTR329_MEAS_RATE);

  ltr329.setPowerUp();
  printAllLTR329Regs();

}

void sensorLoop(){

  THPSensorLoop();
  if(DISPLAY_HAS_LIGHT_SENSOR) {
    AmbLightSensorLoop();
  }
}

void THPSensorLoop() {

  static int lastMillis = 0;
  int nowMillis = millis();
  //take a sample every 10min to avoid self heating
  if(lastMillis==0 || (nowMillis > (lastMillis + 600000)) || nowMillis < lastMillis){
    //read BME sensor
    bme280.begin();
    P = bme280.readFloatPressure() * 0.0002953; //read Pa and convert to inHg
    F = bme280.readTempF();
    H = bme280.readFloatHumidity();
    bme280.writeRegister(BME280_CTRL_MEAS_REG, 0x00); //sleep the BME280
        nodeInfo[SENSORID].count = nodeInfo[SENSORID].count + 1;

    if(nodeInfo[SENSORID].THP == 0) {
      nodeInfo[SENSORID].THP = new _GDnode_t;
    }
    nodeInfo[SENSORID].THP->RSSI = String("0");
    nodeInfo[SENSORID].THP->BAT = String("4.0v");
    nodeInfo[SENSORID].senderID = SENSORID;
    nodeInfo[SENSORID].targetID = 1; //packets are always sent to node 1 (the gateway)
    nodeInfo[SENSORID].messageID = 1; //default value to fully populate struct
    nodeInfo[SENSORID].packetID = 0; //zero means we arent participating in missing/duplicate packet checks

    if(!nodeList.nodeExists(SENSORID)){
      nodeList.insertNode(SENSORID);
    }
    char tmpStr[10];
    dtostrf(F, 3,2, tmpStr);
    nodeInfo[SENSORID].THP->F = String(tmpStr);
    dtostrf(H, 3,2, tmpStr);
    nodeInfo[SENSORID].THP->H = String(tmpStr);
    dtostrf(P, 3,2, tmpStr);
    nodeInfo[SENSORID].THP->P = String(tmpStr);

    lastMillis = nowMillis;
    DEBUG_MSG("[SENSOR] Reading - F:%s H:%s P:%s\n", nodeInfo[SENSORID].THP->F.c_str(), nodeInfo[SENSORID].THP->H.c_str(), nodeInfo[SENSORID].THP->P.c_str());

    sendSensorData();
  }

}

void AmbLightSensorLoop(){
  static int lastMillis = 0;
  int nowMillis = millis();
  //take a reading every 10sec
  if(lastMillis==0 || (nowMillis > (lastMillis + 4000)) || nowMillis < lastMillis){
    lastMillis = nowMillis;

    ltr329.begin();
    //printAllLTR329Regs();

    bool reset, mode;
    byte gain;
    ltr329.getControl(gain, reset, mode);

    if(!mode){
      //This shouldnt happen after initialization, but if it does the sensor needs to be reconfigured to collect data.
      DEBUG_MSG("[SENSOR] LTR-329 mode inactive. Setting registers\n");
      setALSensor();
    }

    // Check if there is new data to be read
    if(ltr329.hasNewData()) {
      //DEBUG_MSG("[SENSOR] LTR-329 has new data\n");
      // Retrieve the data from the device:
      unsigned int data0, data1;
      if (ltr329.getData(data0,data1)) {
        // getData() returned true, communication was successful
        double lux;    // Resulting lux value
        if(ltr329.getLux(LTR329_GAIN,LTR329_INT_TIME,data0,data1,lux)) {

          //Using data0 here (Visible + IR light) due to jumpiness of lux calc. The two channels have some
          //lag between them and this causes lux to swing wildly.
          double new_sample = data0;
          avgLight -= avgLight/LTR329_ROLLING_AVG_SIZE;
          avgLight += new_sample/LTR329_ROLLING_AVG_SIZE;

          //DEBUG_MSG("[SENSOR] V+IR: %i IR: %i Avg Light: %4.1f\n", data0, data1, avgLight);
        }    
      }
      else {
        // getData() returned false because of an I2C error, inform the user.
        byte error = ltr329.getError();
        printI2CError(error);
      }
    }
  }
}

void printAllLTR329Regs() {
        bool valid, intrStatus, dataStatus, reset, mode;
        byte gain, intTime, measRate;
        ltr329.getStatus(valid, gain, intrStatus, dataStatus);

        ltr329.getControl(gain, reset, mode);

        ltr329.getMeasurementRate(intTime, measRate);

        DEBUG_MSG("[SENSOR] LTR-329 registers contain - gain: %i, reset: %i, mode: %i, ", gain, reset, mode);
        DEBUG_MSG("intTime: %i, measRate: %i, ", intTime, measRate);
        DEBUG_MSG("valid: %i, intrStatus: %i, dataStatus: %i\n", valid, intrStatus, dataStatus);
}

double getAvgLight() {
  return avgLight;
}

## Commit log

2018-10-31 Initial commit under VSCode to new GW repo, SensorIoT-GW. Based on firmware ver 1.0.4
    [BME280_Daughter.brd, BME280_Daughter.sch, BME280_Daughter_1_1.brd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]
2018-11-05 Changed AP Mode display info, also increase wifi reconnect timer to 10min. Should allow easier editing of network info during initial config
    [GDEnvSensorNode_1_3b.brd, GDEnvSensorNode_1_3b.sch, GDEnvSensorNode_1_4b.brd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]
2018-12-20 v1.0.5 - bug fix for time display jitter, change topic matching to use strings, reorganize folders
    [GDEnvSensorGW_1_15.brd]
2019-03-28 Reverse FPC connector wiring to support new cables
    [BME280_Daughter_1_2.brd, BME280_Daughter_1_2.sch]
2019-03-28 v1.0.9 features: display redesign and web config.
    [display.ino, main.ino, web.ino]
2019-03-28 fix to clientID and checkbox setting update
    [mqtt.ino]
2019-06-18 Version 1.15 of GW board
    [GDEnvSensorGW_1_15.brd, GDEnvSensorGW_1_15.sch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]
2019-10-18 New vertical USB connector
    [GDEnvSensorGW_1_16.brd, GDEnvSensorGW_1_16.sch]
2019-11-10 cleanup, fix compile warnings
    [display.ino, main.ino, sensor.ino]
2019-11-19 Only reset wifi if wifi config changes
    [web.ino]
2019-11-19 Disable local DNS due to memory leak
    [wifi.ino]
2026-03-19 Consolidate embedded firmware and hardware into unified repo
    Restructure to absorb SensorIoT-Node and SensorIoT-Display:
    - firmware/gateway/ - ESP8266 gateway (moved from firmware root)
    - firmware/node/ - ATmega328P sensor nodes (from SensorIoT-Node)
    - firmware/display/ - ESP32 display module (from SensorIoT-Display)
    - PCBs/gateway/ - Gateway board designs (reorganized)
    - PCBs/node/ - Sensor node board designs (from SensorIoT-Node)
    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

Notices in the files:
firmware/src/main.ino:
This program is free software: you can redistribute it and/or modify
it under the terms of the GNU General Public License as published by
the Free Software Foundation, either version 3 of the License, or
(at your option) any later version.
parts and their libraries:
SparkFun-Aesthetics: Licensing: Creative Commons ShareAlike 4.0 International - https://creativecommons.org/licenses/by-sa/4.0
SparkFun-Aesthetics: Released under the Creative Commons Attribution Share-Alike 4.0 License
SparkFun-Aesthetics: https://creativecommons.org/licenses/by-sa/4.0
